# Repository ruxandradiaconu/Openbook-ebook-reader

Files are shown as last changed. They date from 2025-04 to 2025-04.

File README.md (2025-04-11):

OpenBook e-book reader
Diaconu Oana-Ruxandra - 331CC

## Diagrama bloc

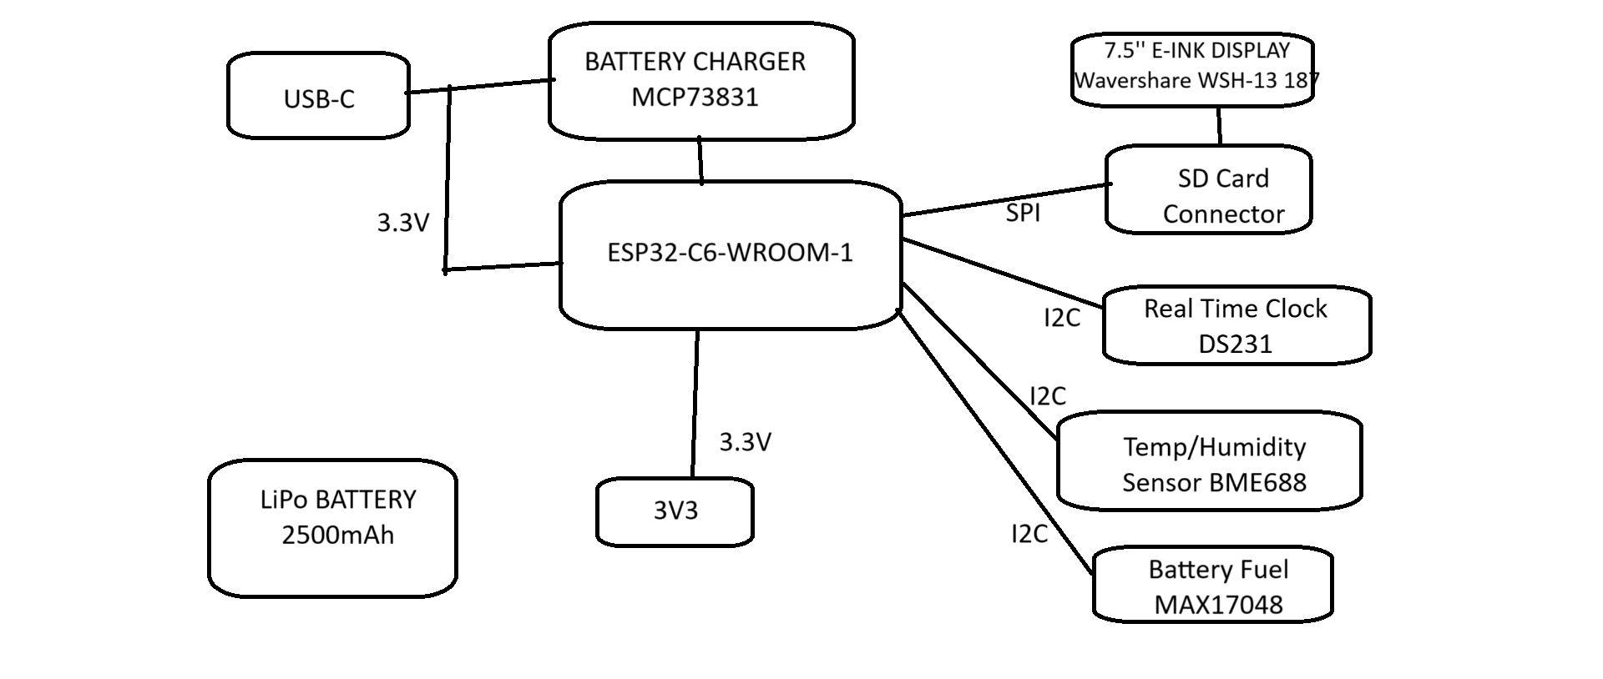
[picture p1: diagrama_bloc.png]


## BOM – Bill of Materials

| Componenta | Link | Datasheet |
|:---|:---|:---|
| 112A-TAAR-R03_ATTEND | https://store.comet.bg/en/Catalogue/Product/43497/ | https://store.comet.bg/en/Catalogue/Product/43497/ |
| 744043680IND_4828-WE-TPC_WRE | https://www.digikey.sg/en/models/1638515 | https://www.digikey.sg/en/models/1638515 |
| ADAFRUIT_LEDCHIP-LED0603 | https://www.snapeda.com/parts/KP-1608SURCK/Kingbright/view-part/?ref=search&t=LED%200603 | https://www.snapeda.com/parts/KP-1608SURCK/Kingbright/datasheet/ |
| BD5229G-TR | https://componentsearchengine.com/part-view/BD5229G-TR/ROHM%20Semiconductor | https://componentsearchengine.com/part-view/BD5229G-TR/ROHM%20Semiconductor |
| BME680 | https://www.snapeda.com/parts/BME680/Bosch/view-part/?welcome=home | https://www.snapeda.com/parts/BME680/Bosch%20Sensortec/datasheet/ |
| BUTTON_CUSYOMV1 | https://industry.panasonic.com/global/en/downloads?tab=cad&small_g_cd=203&part_no=EVQPUJ02K | https://industry.panasonic.com/global/en/downloads?tab=catalog&small_g_cd=203&part_no=EVQPUJ02K |
| CC0402MRX5R5BB106 | https://componentsearchengine.com/part-view/CC0402MRX5R5BB106/YAGEO | https://componentsearchengine.com/part-view/CC0402MRX5R5BB106/YAGEO |
| CPH3225A | https://www.snapeda.com/parts/CPH3225A/Seiko+Instruments/view-part/?ref=eda | https://www.snapeda.com/parts/CPH3225A/Seiko%20Instruments/datasheet/ |
| DS3231SN | https://www.snapeda.com/parts/DS3231SN%23/Analog+Devices/view-part/?ref=eda | https://www.snapeda.com/parts/DS3231SN%23/Analog%20Devices/datasheet/ |
| 7.5in E-ink Display | https://grabcad.com/library/7-5in-e-ink-display-assortment-1 | https://grabcad.com/library/7-5in-e-ink-display-assortment-1 |
| ESP32-C6-WROOM-1-N8 | https://www.snapeda.com/parts/ESP32-C6-WROOM-1-N8/Espressif+Systems/view-part/?ref=eda | https://www.snapeda.com/parts/ESP32-C6-WROOM-1-N8/Espressif%20Systems/datasheet/ |
| ESP32C6_VARISTORCN1812 | https://www.mouser.co.uk/ProductDetail/EPCOS-TDK/B72520T0350K062 | https://www.mouser.co.uk/ProductDetail/EPCOS-TDK/B72520T0350K062 |
| ESP32_WROVER_BME680_BME680 | https://www.snapeda.com/parts/BME680/Bosch/view-part/?welcome=home | https://www.snapeda.com/parts/BME680/Bosch%20Sensortec/datasheet/ |
| ESP32_WROVER_EAGLE-LTSPICE_CC0402 | https://componentsearchengine.com/part-view/CC0402MRX5R5BB106/YAGEO | https://componentsearchengine.com/Datasheets/2/CC0402MRX5R5BB106.pdf |
| ESP32_WROVER_EAGLE-LTSPICE_RR0402 | https://www.snapeda.com/parts/RC0402FR-07226RL/Yageo/view-part/ | https://www.snapeda.com/parts/RC0402FR-07226RL/Yageo/datasheet/ |
| ESP32_WROVER_SPARKFUN-DISCRETESEMI_MOSFET_PCH-DMG2305UX-7 | https://componentsearchengine.com/part-view/DMG2305UX-7/Diodes%20Incorporated | https://componentsearchengine.com/part-view/DMG2305UX-7/Diodes%20Incorporated |
| FH34SRJ-24S-0.5SH_99_ | https://componentsearchengine.com/part-view/XC6220A331MR-G/Torex |  https://componentsearchengine.com/part-view/XC6220A331MR-G/Torex |
| MAX17048G+T10 | https://www.snapeda.com/parts/MAX17048G+T10/Analog+Devices/view-part/?ref=eda | https://www.snapeda.com/parts/MAX17048G+T10/Analog%20Devices/datasheet/ |
| MBR0530 | https://ro.mouser.com/ProductDetail/KYOCERA-AVX/SD0805S020S1R0 | https://ro.mouser.com/datasheet/2/40/schottky-3165252.pdf |
| MCP73831 | https://www.digikey.com/en/models/1874108 | https://www.digikey.com/en/models/1874108 |
| PGB1010603MR | https://www.snapeda.com/parts/PGB1010603MR/Littelfuse/view-part/?ref=eda | https://www.snapeda.com/parts/PGB1010603MR/Littelfuse%20Inc./datasheet/ |
| QWIIC_CONNECTORJS-1MM | https://www.snapeda.com/parts/PRT-14417/SparkFun/view-part/ | https://www.snapeda.com/parts/PRT-14417/SparkFun%20Electronics/datasheet/ |
| RCL-CT3528 | https://stud33302.autodesk360.com/g/shares/SH30dd5QT870c25f12fc6065d74bcaa3bf24 | https://stud33302.autodesk360.com/g/shares/SH30dd5QT870c25f12fc6065d74bcaa3bf24 |
| SAMACSYS_PARTS_USB4110-GF-A | https://componentsearchengine.com/part-view/USB4110-GF-A/GCT%20(GLOBAL%20CONNECTOR%20TECHNOLOGY) | https://componentsearchengine.com/part-view/USB4110-GF-A/GCT%20(GLOBAL%20CONNECTOR%20TECHNOLOGY) |
| SI1308EDL-T1-GE3 | https://componentsearchengine.com/part-view/SI1308EDL-T1-GE3/Vishay | https://componentsearchengine.com/Datasheets/1/SI1308EDL-T1-GE3.pdf |
| SJ | https://grabcad.com/library/solder-jumpers-1 | https://grabcad.com/library/solder-jumpers-1 |
| USBLC6-2SC6Y | https://www.snapeda.com/parts/USBLC6-2SC6Y/STMicroelectronics/view-part/?ref=eda | https://www.snapeda.com/parts/USBLC6-2SC6Y/STMicroelectronics/datasheet/ |
| W25Q512JVEIQ | https://www.snapeda.com/parts/W25Q512JVEIQ/Winbond+Electronics/view-part/?ref=eda | https://www.snapeda.com/parts/W25Q512JVEIQ/Winbond%20Electronics/datasheet/ |
| XC6220A331MR-G | https://componentsearchengine.com/part-view/XC6220A331MR-G/Torex | https://componentsearchengine.com/part-view/XC6220A331MR-G/Torex |

## Descriere functionalitati hardware

###  **E-paper Display**
  - Conectat prin pinii MOSI, SCK, CS, DC, BUSY, RST
  - Permite afișarea conținutului static cu consum energetic extrem de redus
  
###  **SD Card**
  - Conectat prin CS, MOSI, MISO, SCK
  - Utilizat pentru stocarea cărților electronice și a configurațiilor

###  **Baterie Li-Po + Fuel Gauge**
  - Alimentarea principală a sistemului, conectată direct prin paduri la PCB
  - Monitorizată prin MAX17048G+T10 conectat pe I2C (SDA, SCL)

###  **BME688**
  - Senzor ambiental pentru temperatură, presiune, umiditate și gaze
  - Comunică prin aceiași pini I2C ca RTC și Fuel Gauge

###  **RTC** 
  - Oferă timp real precis, cu pin INT pentru întreruperi și pin de reset 
  - Alimentat separat prin VRTC

###  **Butoane fizice**
  - BOOT, IO_CHANGE și RESET
  - Permite controlul funcțiilor precum trecerea între pagini, pornirea dispozitivului, sau activarea bootloader-ului pentru upload firmware

###  **USB-C Conector**
  - Permite programarea și încărcarea dispozitivului.
  - Include protecții ESD și varistor pentru protecția circuitului.

### Specificații de comunicație:

- **SPI** pentru SD card, display și memorie NOR Flash.
- **I2C** pentru RTC, senzor BME688 și fuel gauge.
- **UART** pentru debug sau comunicație serială externă.

### Estimare consum:

- În regim activ: între 80–150 mA (în funcție de e-paper și senzorii activi).
- În standby (deep sleep): sub 1 mA.
- Display-ul e-paper nu consumă curent în regim static – doar la refresh.

## Corespondenta pini ESP32-C6 - restul componentelor

| Pin ESP32-C6 | Nume net / semnal | Componentă asociată | Funcție / Motivare |
|---|---|---|---|
| GPIO0 | IO/BOOT | Buton BOOT | Activare bootloader pentru flash |
| GPIO1 | SS_SD | SD Card | Chip select pentru card SD |
| GPIO3 | MOSI | SD Card + E-Paper | Comunicare SPI |
| GPIO4 | MISO | SD Card | Citire date SPI |
| GPIO5 | SCK | SD Card + E-Paper | Clock SPI |
| GPIO6 | EPD_CS | E-Paper Display | Selectare ecran SPI |
| GPIO7 | EPD_DC | E-Paper Display | Data/Command pentru ecran |
| GPIO8 | EPD_BUSY | E-Paper Display | Semnal BUSY de la ecran |
| GPIO9 | EPD_RST | E-Paper Display | Reset hardware ecran |
| GPIO10 | FLASH_CS | NOR Flash W25Q512 | Chip select memorie SPI |
| GPIO16 | TXD0 | UART Serial | Transmisie serială |
| GPIO17 | RXD0 | UART Serial | Recepție serială |
| GPIO18 | SDA | RTC, BME688, Fuel Gauge | I2C Data |
| GPIO19 | SCL | RTC, BME688, Fuel Gauge | I2C Clock |
| GPIO20 | INT_RTC | RTC | Interrupere alarmă |
| GPIO21 | IO/CHANGE | Buton IO_CHANGE | Detecție apăsare buton |
| GPIO22 | RTC_RST | RTC | Reset RTC |
| GPIO23 | VRTC | RTC | Tensiune RTC |
| GPIO44 | RESE | Reset ESP / Sisteme externe | Reset logic suplimentar |
| GPIO45 | GDR | E-Paper Driver | Gate Driver enable |

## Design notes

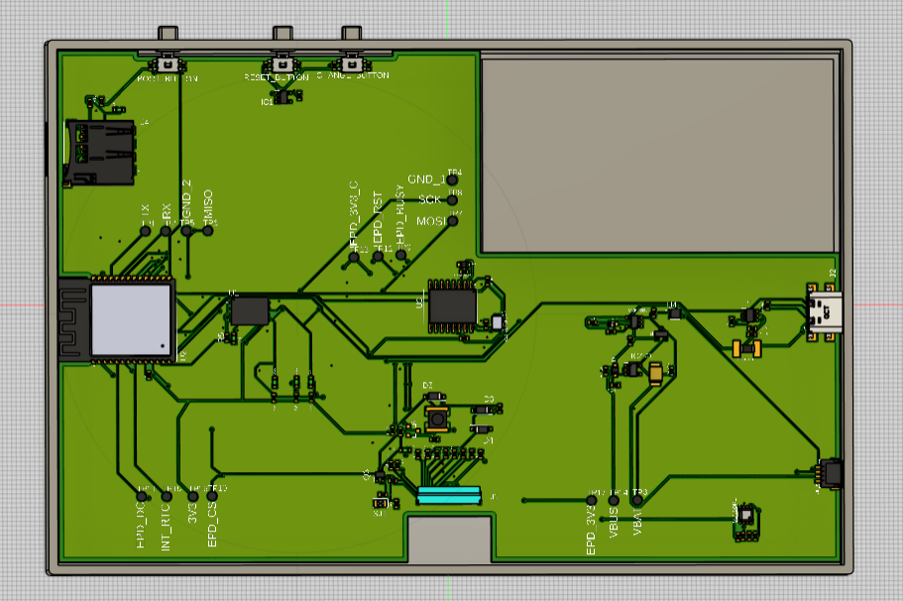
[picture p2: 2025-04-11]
Images/final_inside_completed.png

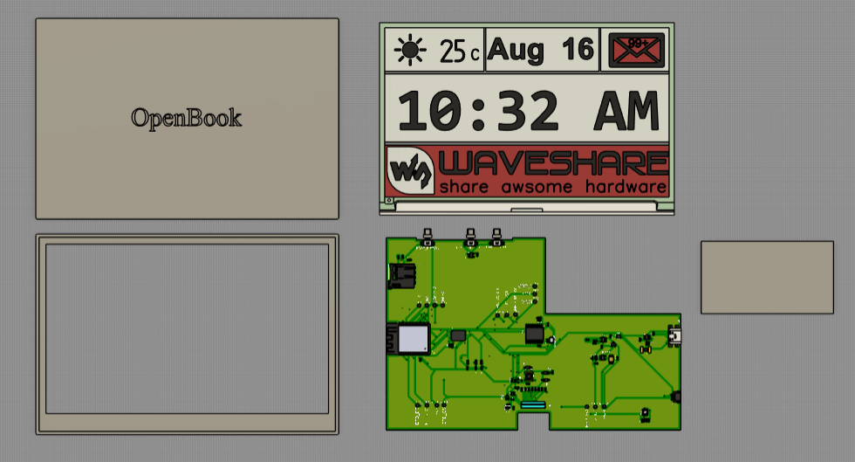
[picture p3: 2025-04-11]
Images/final_exploded_view.png

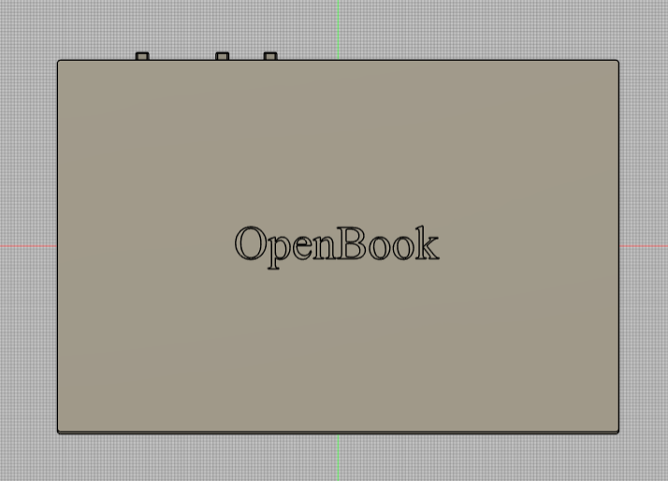
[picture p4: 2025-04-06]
Images/Screenshot 2025-04-06 185446.png

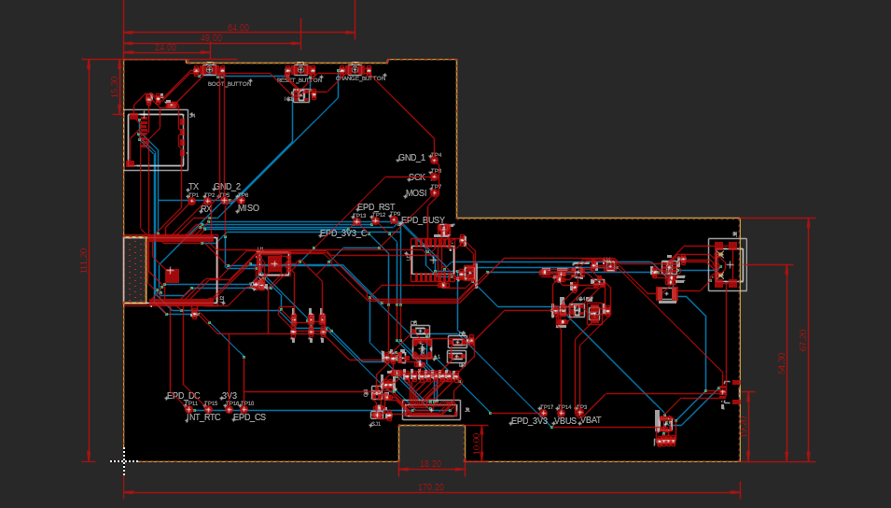
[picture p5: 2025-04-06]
Images/Screenshot 2025-04-06 185516.png

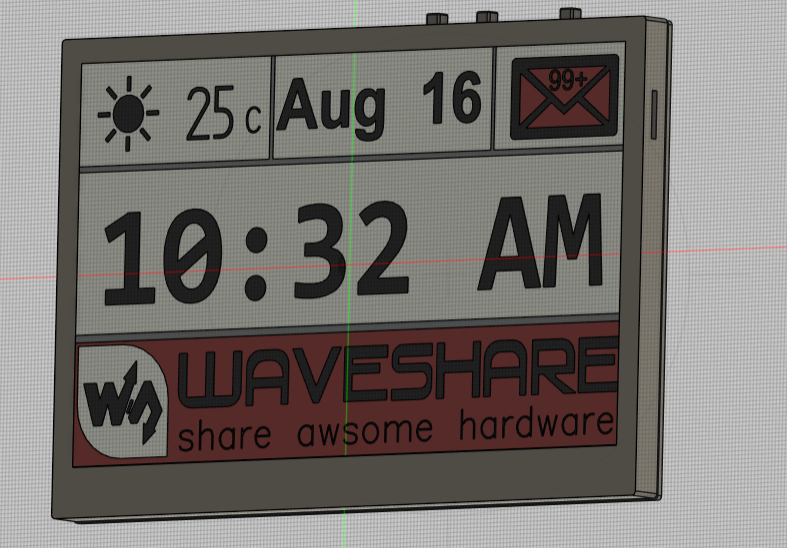
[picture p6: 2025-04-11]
Images/final_display_view.png

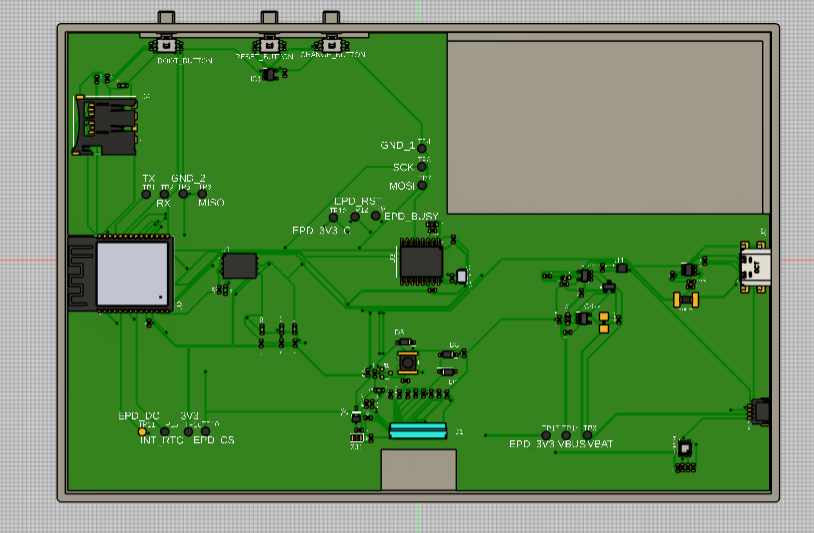
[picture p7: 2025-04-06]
Images/Screenshot 2025-04-06 185214.png

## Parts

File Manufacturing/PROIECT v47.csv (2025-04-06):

Qty | Value | Device | Package | Parts | Description | 3D_3V3 | 3D_EPD_3V3 | 3D_EPD_3V3_C | 3D_EPD_BUSY | 3D_EPD_CS | 3D_EPD_DC | 3D_EPD_RST | 3D_GND | 3D_GND2 | 3D_INT_RTC | 3D_MISO | 3D_MOSI | 3D_RX | 3D_SCK | 3D_TX | 3D_VBAT | 3D_VBUS | ARROW_PART_NUMBER | ARROW_PRICE-STOCK | AVAILABILITY | CENTROID_NOT_SPECIFIED | CHECK_PRICES | COPYRIGHT | DATASHEET | DESCRIPTION | DIGIKEY_DESCRIPTION | DIGIKEY_PART_NUMBER | DMG2305UX-7 | HEIGHT | LEAD_FREE | MANUFACTURER_NAME | MANUFACTURER_PART_NUMBER | MF | MFR_NAME | MOUSER_PART_NUMBER | MOUSER_PRICE-STOCK | MOUSER_TESTING_PART_NUMBER | MOUSER_TESTING_PRICE-STOCK | MP | MPN | PACKAGE | POPULARITY | PREFIX | PRICE | PROD_ID | PURCHASE-URL | ROHS | SNAPEDA_LINK | SPICEMODEL | SPICEPREFIX | TEMPERATURE_RANGE_HIGH | TEMPERATURE_RANGE_LOW | TP_SIGNAL_NAME | VALUE
1 |  | ADAFRUIT_LEDCHIP-LED0603 | ADAFRUIT_CHIP-LED0603 | CHG_LED | LED
3 |  | BUTTON_CUSYOMV1 | MYBUTTON | BOOT_BUTTON, CHANGE_BUTTON, RESET_BUTTON
3 |  | MBR0530''' | SOD3716X135N | D3, D4, D5 | ON SEMICONDUCTOR - MBR0530 - DIODE, SCHOTTKY, 0.5A, 30V, SOD-123
1 |  | SJ | SJ | SJ1 | SMD solder JUMPER |  |  |  |  |  |  |  |  |  |  |  |  |  |  |  |  |  |  |  |  |  |  |  |  |  |  |  |  |  |  |  |  |  |  |  |  |  |  |  |  |  | 3
1 | 0.1uF/50V | EAGLE-LTSPICE_CC0402 | EAGLE-LTSPICE_C0402 | EPD_C5 | CAPACITOR, European symbol |  |  |  |  |  |  |  |  |  |  |  |  |  |  |  |  |  |  |  |  |  |  |  |  |  |  |  |  |  |  |  |  |  |  |  |  |  |  |  |  |  |  |  |  |  |  |  |  | NONE | C
1 | 0.47 | ESP32_WROVER_EAGLE-LTSPICE_R | ESP32_WROVER_EAGLE-LTSPICE_R0402 | R3 | RESISTOR, European symbol
1 | 100k | ESP32_WROVER_EAGLE-LTSPICE_R | ESP32_WROVER_EAGLE-LTSPICE_R0402 | R1_PWRUSB | RESISTOR, European symbol
6 | 100nF | EAGLE-LTSPICE_CC0402 | EAGLE-LTSPICE_C0402 | C5, C6, C8, C9, C10, C_DELAY | CAPACITOR, European symbol |  |  |  |  |  |  |  |  |  |  |  |  |  |  |  |  |  |  |  |  |  |  |  |  |  |  |  |  |  |  |  |  |  |  |  |  |  |  |  |  |  |  |  |  |  |  |  |  | NONE | C
3 | 100nF | ESP32_WROVER_EAGLE-LTSPICE_C | ESP32_WROVER_EAGLE-LTSPICE_C0402 | C1, C2, C4_USB | CAPACITOR, European symbol
1 | 100uF TANT | RCL_CPOL-EUCT3528 | RCL_CT3528 | C3 | POLARIZED CAPACITOR, European symbol |  |  |  |  |  |  |  |  |  |  |  |  |  |  |  |  |  |  |  |  |  |  |  |  |  |  |  |  |  |  |  |  |  |  |  |  |  |  |  |  |  | 0 |  |  |  |  |  |  |  | C
16 | 10K | ESP32_WROVER_EAGLE-LTSPICE_R | ESP32_WROVER_EAGLE-LTSPICE_R0402 | R1, R1_PINH, R1_PINH1, R2_PINH, R2_PINH1, R4, R5, R6, R7, R8, R9, R10, R_BOOT, R_CHANGE, R_CL1, R_RESET | RESISTOR, European symbol
1 | 10uF | EAGLE-LTSPICE_CC0402 | EAGLE-LTSPICE_C0402 | C7 | CAPACITOR, European symbol |  |  |  |  |  |  |  |  |  |  |  |  |  |  |  |  |  |  |  |  |  |  |  |  |  |  |  |  |  |  |  |  |  |  |  |  |  |  |  |  |  |  |  |  |  |  |  |  | NONE | C
1 | 112A-TAAR-R03_ATTEND | 112A-TAAR-R03_ATTEND | 112ATAARR03ATTEND | J4 | Micro SD Card Socket, Push-Push Type, Top Mount, SMT, H=1.83mm, 10u |  |  |  |  |  |  |  |  |  |  |  |  |  |  |  |  |  |  |  |  |  |  |  |  | Micro SD Card Socket | Push-Push Type | Top Mount | SMT | H=1.83mm | 10u |  |  |  | 1.9mm |  | ATTEND | 112A-TAAR-R03 ATTEND
1 | 15 | ESP32_WROVER_EAGLE-LTSPICE_R | ESP32_WROVER_EAGLE-LTSPICE_R0402 | R_CAPACITOR | RESISTOR, European symbol
9 | 1uF/50V | EAGLE-LTSPICE_CC0402 | EAGLE-LTSPICE_C0402 | EPD_C1, EPD_C2, EPD_C6, EPD_C7, EPD_C8, EPD_C9, EPD_C10, EPD_C11, EPD_C12 | CAPACITOR, European symbol |  |  |  |  |  |  |  |  |  |  |  |  |  |  |  |  |  |  |  |  |  |  |  |  |  |  |  |  |  |  |  |  |  |  |  |  |  |  |  |  |  |  |  |  |  |  |  |  | NONE | C
1 | 2.2 | ESP32_WROVER_EAGLE-LTSPICE_R | ESP32_WROVER_EAGLE-LTSPICE_R0402 | R2 | RESISTOR, European symbol
1 | 200 | ESP32_WROVER_EAGLE-LTSPICE_R | ESP32_WROVER_EAGLE-LTSPICE_R0402 | R1_BAT | RESISTOR, European symbol
2 | 20V/4.2A/52mO/1.4W | ESP32_WROVER_SPARKFUN-DISCRETESEMI_MOSFET_PCH-DMG2305UX-7 | ESP32_WROVER_SPARKFUN-DISCRETESEMI_SOT23-3 | Q1, Q2 | P-channel MOSFETs |  |  |  |  |  |  |  |  |  |  |  |  |  |  |  |  |  |  |  |  |  |  |  |  |  |  |  |  |  |  |  |  |  |  |  |  |  |  |  |  |  |  |  |  | TRAN-14388 |  |  |  |  |  |  |  |  | 20V/4.2A/52mO/1.4W
1 | 2K | ESP32_WROVER_EAGLE-LTSPICE_R | ESP32_WROVER_EAGLE-LTSPICE_R0402 | R2_BAT | RESISTOR, European symbol
2 | 4.7uF | EAGLE-LTSPICE_CC0402 | EAGLE-LTSPICE_C0402 | C1_BAT, C2_BAT | CAPACITOR, European symbol |  |  |  |  |  |  |  |  |  |  |  |  |  |  |  |  |  |  |  |  |  |  |  |  |  |  |  |  |  |  |  |  |  |  |  |  |  |  |  |  |  |  |  |  |  |  |  |  | NONE | C
3 | 4.7uF | ESP32_WROVER_EAGLE-LTSPICE_C | ESP32_WROVER_EAGLE-LTSPICE_C0402 | C1_BAT1, C1_BAT2, C5_USB | CAPACITOR, European symbol
1 | 4.7uF/25V | EAGLE-LTSPICE_CC0402 | EAGLE-LTSPICE_C0402 | C4 | CAPACITOR, European symbol |  |  |  |  |  |  |  |  |  |  |  |  |  |  |  |  |  |  |  |  |  |  |  |  |  |  |  |  |  |  |  |  |  |  |  |  |  |  |  |  |  |  |  |  |  |  |  |  | NONE | C
2 | 5K1 | ESP32_WROVER_EAGLE-LTSPICE_R | ESP32_WROVER_EAGLE-LTSPICE_R0402 | R2-USB1, R2_USB | RESISTOR, European symbol
1 | 68uH | 744043680IND_4828-WE-TPC_WRE | IND_4828-WE-TPC_WRE | L1 |  |  |  |  |  |  |  |  |  |  |  |  |  |  |  |  |  |  |  |  |  |  |  | Copyright (C) 2024 Ultra Librarian. All rights reserved. |  |  |  |  |  |  |  |  | 744043680 |  | Wurth Electronics
1 | BD5229G-TR | BD5229G-TR | SOT95P280X125-5N | IC1 | Voltage Detector with Adjustable Delay Time: CMOS processes are utilized to develop high precision, low current consumption CMOS reset ICs that allow arbitrary setting of the delay time. The extensive lineup includes both Nch Open Drain and CMOS output types in a wide range of detection voltages (from 2.3V to 6.0V, in 0.1V steps), enabling selection of the ideal solution based on customer requirements. In addition, the entire series is of course both lead-free and RoHS-compliant. |  |  |  |  |  |  |  |  |  |  |  |  |  |  |  |  |  |  |  |  |  |  |  |  | Voltage Detector with Adjustable Delay Time: CMOS processes are utilized to develop high precision | low current consumption CMOS reset ICs that allow arbitrary setting of the delay time. The extensive lineup includes both Nch Open Drain and CMOS output types in a wide range of detection voltages (from 2.3V to 6.0V | in 0.1V steps) | enabling selection of the ideal solution based on customer requirements. In addition | the entire series is of course both lead-free and RoHS-compliant. |  |  |  | 1.25mm |  | ROHM Semiconductor | BD5229G-TR |  |  | 755-BD5229G-TR | https://www.mouser.co.uk/ProductDetail/ROHM-Semiconductor/BD5229G-TR?qs=4kLU8WoGk0vvnhrrYwdszw%3D%3D
1 | CPH3225A | CPH3225A | CAPCP3225X100N | C10_SUPERCAP | Cap 0.011F 3.3V 1210 Flat Check availability |  |  |  |  |  |  |  |  |  |  |  |  |  |  |  |  |  |  |  | Not in stock |  | https://www.snapeda.com/parts/CPH3225A/Seiko+Instruments/view-part/?ref=eda |  |  | 11 mF (EDLC) Supercapacitor 3.3 V 1210 (3225 Metric) - - |  |  |  |  |  |  |  | Seiko Instruments |  |  |  |  |  | CPH3225A |  | 1210 Seiko |  |  | None |  | https://www.snapeda.com/api/url_track_click_mouser/?unipart_id=562593&manufacturer=Seiko Instruments&part_name=CPH3225A&search_term=None |  | https://www.snapeda.com/parts/CPH3225A/Seiko+Instruments/view-part/?ref=snap
1 | DS3231SN# | DS3231SN# | SOIC127P1032X265-16N | U3 | Real Time Clock Serial 16-Pin SOIC W T/R Check availability |  |  |  |  |  |  |  |  |  |  |  |  |  |  |  |  |  |  |  | In Stock |  | https://www.snapeda.com/parts/DS3231SN%23/Analog+Devices/view-part/?ref=eda |  |  | Extremely Accurate I²C-Integrated RTC/TCXO/Crystal |  |  |  |  |  |  |  | Analog Devices |  |  |  |  |  | DS3231SN# |  | SOIC-16 Maxim |  |  | None |  | https://www.snapeda.com/api/url_track_click_mouser/?unipart_id=99048&manufacturer=Analog Devices&part_name=DS3231SN#&search_term=None |  | https://www.snapeda.com/parts/DS3231SN%23/Analog+Devices/view-part/?ref=snap
1 | ESP32-C6-WROOM-1-N8 | ESP32-C6-WROOM-1-N8 | XCVR_ESP32-C6-WROOM-1-N8 | U2 | Check availability |  |  |  |  |  |  |  |  |  |  |  |  |  |  |  |  |  |  |  | In Stock |  | https://www.snapeda.com/parts/ESP32-C6-WROOM-1-N8/Espressif+Systems/view-part/?ref=eda |  |  | Multiprotocol Modules ESP32-C6 module | Wi-Fi 6 in 2.4 GHz band | Bluetooth 5 | Zigbee 3.0 and Thread. ESP34-WROOM Compatible - ENGINEERING SAMPLE |  |  |  |  |  |  |  | Espressif Systems |  |  |  |  |  | ESP32-C6-WROOM-1-N8 |  | None |  |  | None |  |  |  | https://www.snapeda.com/parts/ESP32-C6-WROOM-1-N8/Espressif+Systems/view-part/?ref=snap
1 | ESP32C6_VARISTORCN1812 | ESP32C6_VARISTORCN1812 | ESP32C6_VARISTOR_CT/CN1812 | PFMF.050.1 | VARISTOR |  |  |  |  |  |  |  |  |  |  |  |  |  |  |  |  |  |  |  |  |  |  |  |  |  |  |  |  |  |  |  |  |  |  |  |  |  |  |  |  |  | 0
2 | ESP32_WROVER_AVX---SD0805S020S1R0_AVX_SD0805S020S1R0_0_0AVX_SD0805S020S1R0_0_0 | ESP32_WROVER_AVX---SD0805S020S1R0_AVX_SD0805S020S1R0_0_0AVX_SD0805S020S1R0_0_0 | ESP32_WROVER_AVX---SD0805S020S1R0_AVX_SD0805S020S1R0_0 | D2, D7 | Schottky Barrier Rectifier Diode |  |  |  |  |  |  |  |  |  |  |  |  |  |  |  |  |  |  |  |  | No |  |  | http://datasheets.avx.com/schottky.pdf |  | DIODE SCHOTTKY 20V 1A 0805 | 478-7800-1-ND |  |  | yes |  |  | AVX |  | 581-SD0805S020S1R0 |  |  |  |  |  | 0805 (2012 metric) |  | D |  |  |  | yes |  |  |  | +125°C | -55°C
1 | ESP32_WROVER_BME680_BME680 | ESP32_WROVER_BME680_BME680 | ESP32_WROVER_BME680_PSON80P300X300X100-8N | SENSOR2 | Integrated Environmental Unit |  |  |  |  |  |  |  |  |  |  |  |  |  |  |  |  |  |  |  | Unavailable |  |  |  |  | Integrated Environmental Unit |  |  |  |  |  |  |  | Bosch Sensortec |  |  |  |  |  | BME680 |  | LGA-8 Bosch Tools |  |  | None
1 | ESP32_WROVER_SPARKFUN-IC-POWER_MCP73831 | ESP32_WROVER_SPARKFUN-IC-POWER_MCP73831 | ESP32_WROVER_SPARKFUN-IC-POWER_SOT23-5 | MCP73831 | MCP73831T Li-Ion, Li-Pol Controller |  |  |  |  |  |  |  |  |  |  |  |  |  |  |  |  |  |  |  |  |  |  |  |  |  |  |  |  |  |  |  |  |  |  |  |  |  |  |  |  |  |  |  |  | IC-09995
1 | FH34SRJ-24S-0.5SH_99_ | FH34SRJ-24S-0.5SH_99_ | FH34SRJ24S05SH99 | J1 | (0.50mm) Surface Mount, Right Angle |  |  |  |  |  |  |  |  |  |  |  |  |  |  |  |  |  |  |  |  |  |  |  |  | 24 Position FFC | FPC Connector Contacts | (0.50mm) Surface Mount | Right Angle |  |  |  | 1.1mm |  | Hirose | FH34SRJ-24S-0.5SH(99) |  |  | 798-FH34SRJ24S05SH99 | https://www.mouser.co.uk/ProductDetail/Hirose-Connector/FH34SRJ-24S-0.5SH99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
1 | MAX17048G+T10 | MAX17048G+T10 | SON50P200X200X80-9N | U4 | Check availability |  |  |  |  |  |  |  |  |  |  |  |  |  |  |  |  |  |  |  | In Stock |  | https://www.snapeda.com/parts/MAX17048G+T10/Analog+Devices/view-part/?ref=eda |  |  | 3µA 1-Cell/2-Cell Fuel Gauge with ModelGauge |  |  |  |  |  |  |  | Analog Devices |  |  |  |  |  | MAX17048G+T10 |  | TDFN-8 Maxim |  |  | None |  | https://www.snapeda.com/api/url_track_click_mouser/?unipart_id=329239&manufacturer=Analog Devices&part_name=MAX17048G+T10&search_term=None |  | https://www.snapeda.com/parts/MAX17048G+T10/Analog+Devices/view-part/?ref=snap
6 | PGB1010603MR''' | PGB1010603MR''' | DIOC1608X36N | D6, D8, D9, D10, D11, D12 | Check availability
1 | QWIIC_RIGHT_ANGLE | QWIIC_CONNECTORJS-1MM | JST04_1MM_RA | J3 | SparkFun I2C Standard Qwiic Connector |  |  |  |  |  |  |  |  |  |  |  |  |  |  |  |  |  |  |  |  |  |  |  |  |  |  |  |  |  |  |  |  |  |  |  |  |  |  |  |  |  |  |  |  | CONN-13694 |  |  |  |  |  |  |  |  | QWIIC_RIGHT_ANGLE
1 | SAMACSYS_PARTS_USB4110-GF-A | SAMACSYS_PARTS_USB4110-GF-A | SAMACSYS_PARTS_USB4110GFA | J2 | CONN USB 2.0 TYPE-C R/A SMT |  |  |  |  |  |  |  |  |  |  |  |  |  |  |  |  |  |  |  |  |  |  |  |  | CONN USB 2.0 TYPE-C R/A SMT |  |  |  | 3.26mm |  | GCT (GLOBAL CONNECTOR TECHNOLOGY) | USB4110-GF-A |  |  | 640-USB4110-GF-A | https://www.mouser.co.uk/ProductDetail/GCT/USB4110-GF-A?qs=KUoIvG%2F9IlYiZvIXQjyJeA%3D%3D
1 | SI1308EDL-T1-GE3 | SI1308EDL-T1-GE3 | SOT65P210X110-3N | Q3 | MOSFET N-Ch 30V 1.5A TrenchFET SC70 Vishay Si1308EDL-T1-GE3 N-channel MOSFET Transistor, 1.5 A, 30 V, 3-Pin SC-70 |  |  |  |  |  |  |  |  |  |  |  |  |  |  |  |  |  |  |  | In Stock |  | https://www.snapeda.com/parts/SI1308EDL-T1-GE3/Vishay+Siliconix/view-part/?ref=eda |  |  | Si1308EDL-T1-GE3 N-channel MOSFET Transistor | 1.5 A | 30 V | 3-Pin SC-70 | Siliconix / Vishay SI1308EDL-T1-GE3 |  |  |  |  |  |  |  | Vishay Siliconix |  |  |  |  |  | SI1308EDL-T1-GE3 |  | SOT-323 Vishay Semiconductor |  |  | None |  | https://www.snapeda.com/api/url_track_click_mouser/?unipart_id=274603&manufacturer=Vishay Siliconix&part_name=SI1308EDL-T1-GE3&search_term=None |  | https://www.snapeda.com/parts/SI1308EDL-T1-GE3/Vishay+Siliconix/view-part/?ref=snap
1 | TPTP20R | TPTP20R | TP20R | TP14 | Test pad |  |  |  |  |  |  |  |  |  |  |  |  |  |  |  |  | VBUS |  |  |  |  |  |  |  |  |  |  |  |  |  |  |  |  |  |  |  |  |  |  |  |  | 2
1 | TPTP20R | TPTP20R | TP20R | TP3 | Test pad |  |  |  |  |  |  |  |  |  |  |  |  |  |  |  | VBAT |  |  |  |  |  |  |  |  |  |  |  |  |  |  |  |  |  |  |  |  |  |  |  |  |  | 2
1 | TPTP20R | TPTP20R | TP20R | TP1 | Test pad |  |  |  |  |  |  |  |  |  |  |  |  |  |  | TX |  |  |  |  |  |  |  |  |  |  |  |  |  |  |  |  |  |  |  |  |  |  |  |  |  |  | 2
1 | TPTP20R | TPTP20R | TP20R | TP8 | Test pad |  |  |  |  |  |  |  |  |  |  |  |  |  | SCK |  |  |  |  |  |  |  |  |  |  |  |  |  |  |  |  |  |  |  |  |  |  |  |  |  |  |  | 2
1 | TPTP20R | TPTP20R | TP20R | TP2 | Test pad |  |  |  |  |  |  |  |  |  |  |  |  | RX |  |  |  |  |  |  |  |  |  |  |  |  |  |  |  |  |  |  |  |  |  |  |  |  |  |  |  |  | 2
1 | TPTP20R | TPTP20R | TP20R | TP7 | Test pad |  |  |  |  |  |  |  |  |  |  |  | MOSI |  |  |  |  |  |  |  |  |  |  |  |  |  |  |  |  |  |  |  |  |  |  |  |  |  |  |  |  |  | 2
1 | TPTP20R | TPTP20R | TP20R | TP6 | Test pad |  |  |  |  |  |  |  |  |  |  | MISO |  |  |  |  |  |  |  |  |  |  |  |  |  |  |  |  |  |  |  |  |  |  |  |  |  |  |  |  |  |  | 2
1 | TPTP20R | TPTP20R | TP20R | TP15 | Test pad |  |  |  |  |  |  |  |  |  | INT_RTC |  |  |  |  |  |  |  |  |  |  |  |  |  |  |  |  |  |  |  |  |  |  |  |  |  |  |  |  |  |  |  | 2
1 | TPTP20R | TPTP20R | TP20R | TP5 | Test pad |  |  |  |  |  |  |  |  | GND_2 |  |  |  |  |  |  |  |  |  |  |  |  |  |  |  |  |  |  |  |  |  |  |  |  |  |  |  |  |  |  |  |  | 2
1 | TPTP20R | TPTP20R | TP20R | TP4 | Test pad |  |  |  |  |  |  |  | GND_1 |  |  |  |  |  |  |  |  |  |  |  |  |  |  |  |  |  |  |  |  |  |  |  |  |  |  |  |  |  |  |  |  |  | 2
1 | TPTP20R | TPTP20R | TP20R | TP12 | Test pad |  |  |  |  |  |  | EPD_RST |  |  |  |  |  |  |  |  |  |  |  |  |  |  |  |  |  |  |  |  |  |  |  |  |  |  |  |  |  |  |  |  |  |  | 2
1 | TPTP20R | TPTP20R | TP20R | TP11 | Test pad |  |  |  |  |  | EPD_DC |  |  |  |  |  |  |  |  |  |  |  |  |  |  |  |  |  |  |  |  |  |  |  |  |  |  |  |  |  |  |  |  |  |  |  | 2
1 | TPTP20R | TPTP20R | TP20R | TP10 | Test pad |  |  |  |  | EPD_CS |  |  |  |  |  |  |  |  |  |  |  |  |  |  |  |  |  |  |  |  |  |  |  |  |  |  |  |  |  |  |  |  |  |  |  |  | 2
1 | TPTP20R | TPTP20R | TP20R | TP9 | Test pad |  |  |  | EPD_BUSY |  |  |  |  |  |  |  |  |  |  |  |  |  |  |  |  |  |  |  |  |  |  |  |  |  |  |  |  |  |  |  |  |  |  |  |  |  | 2
1 | TPTP20R | TPTP20R | TP20R | TP13 | Test pad |  |  | EPD_3V3_C |  |  |  |  |  |  |  |  |  |  |  |  |  |  |  |  |  |  |  |  |  |  |  |  |  |  |  |  |  |  |  |  |  |  |  |  |  |  | 2
1 | TPTP20R | TPTP20R | TP20R | TP17 | Test pad |  | EPD_3V3 |  |  |  |  |  |  |  |  |  |  |  |  |  |  |  |  |  |  |  |  |  |  |  |  |  |  |  |  |  |  |  |  |  |  |  |  |  |  |  | 2
1 | TPTP20R | TPTP20R | TP20R | TP16 | Test pad | 3V3 |  |  |  |  |  |  |  |  |  |  |  |  |  |  |  |  |  |  |  |  |  |  |  |  |  |  |  |  |  |  |  |  |  |  |  |  |  |  |  |  | 2
1 | USBLC6-2SC6Y | USBLC6-2SC6Y | SOT95P280X145-6N | D1 | Low Cap. ESD Protection Auto SOT-23-6 STMicroelectronics USBLC6-2SC6Y, Dual Uni-Directional TVS Diode Array, 6-Pin SOT-23 |  |  |  |  |  |  |  |  |  |  |  |  |  |  |  |  |  |  |  | In Stock |  | https://www.snapeda.com/parts/USBLC6-2SC6Y/STMicroelectronics/view-part/?ref=eda |  |  | 17V Clamp 5A (8/20µs) Ipp Tvs Diode Surface Mount SOT-23-6 |  |  |  |  |  |  |  | STMicroelectronics |  |  |  |  |  | USBLC6-2SC6Y |  | SOT-23-6 STMicroelectronics |  |  | None |  |  |  | https://www.snapeda.com/parts/USBLC6-2SC6Y/STMicroelectronics/view-part/?ref=snap
1 | W25Q512JVEIQ | W25Q512JVEIQ | SON127P600X800X80-9N | U1 | Check availability |  |  |  |  |  |  |  |  |  |  |  |  |  |  |  |  |  |  |  | In Stock |  | https://www.snapeda.com/parts/W25Q512JVEIQ/Winbond+Electronics/view-part/?ref=eda |  |  | FLASH - NOR Memory IC 512Mb (64M x 8) SPI - Quad I/O 133 MHz 8-WSON (8x6) |  |  |  |  |  |  |  | Winbond Electronics |  |  |  |  |  | W25Q512JVEIQ |  | Package |  |  | None |  |  |  | https://www.snapeda.com/parts/W25Q512JVEIQ/Winbond+Electronics/view-part/?ref=snap
1 | XC6220A331MR-G | XC6220A331MR-G | SOT95P280X120-5N | IC4 | LDO Voltage Regulators |  |  |  |  |  |  |  |  |  |  |  |  |  |  |  |  |  |  |  |  |  |  |  |  | LDO Voltage Regulators |  |  |  | 1.2mm |  | Torex | XC6220A331MR-G |  |  | 865-XC6220A331MR-G | https://www.mouser.co.uk/ProductDetail/Torex-Semiconductor/XC6220A331MR-G?qs=AsjdqWjXhJ8ZSWznL1J0gg%3D%3D

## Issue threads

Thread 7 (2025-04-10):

Pcb 2D - Poligon

mariadobre1, 2025-04-10:
Suprafața de sub antena modulului ESP32 nu trebuie inclusă în planul de masă și nu este voie să se ruteze semnale pe sub antenă.
Suprafața PCB-ului de sub antena modulului ESP32 trebuie decupată pentru a crea cât mai puține interferențe cu semnalul radio
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

Closed 2025-04-11.

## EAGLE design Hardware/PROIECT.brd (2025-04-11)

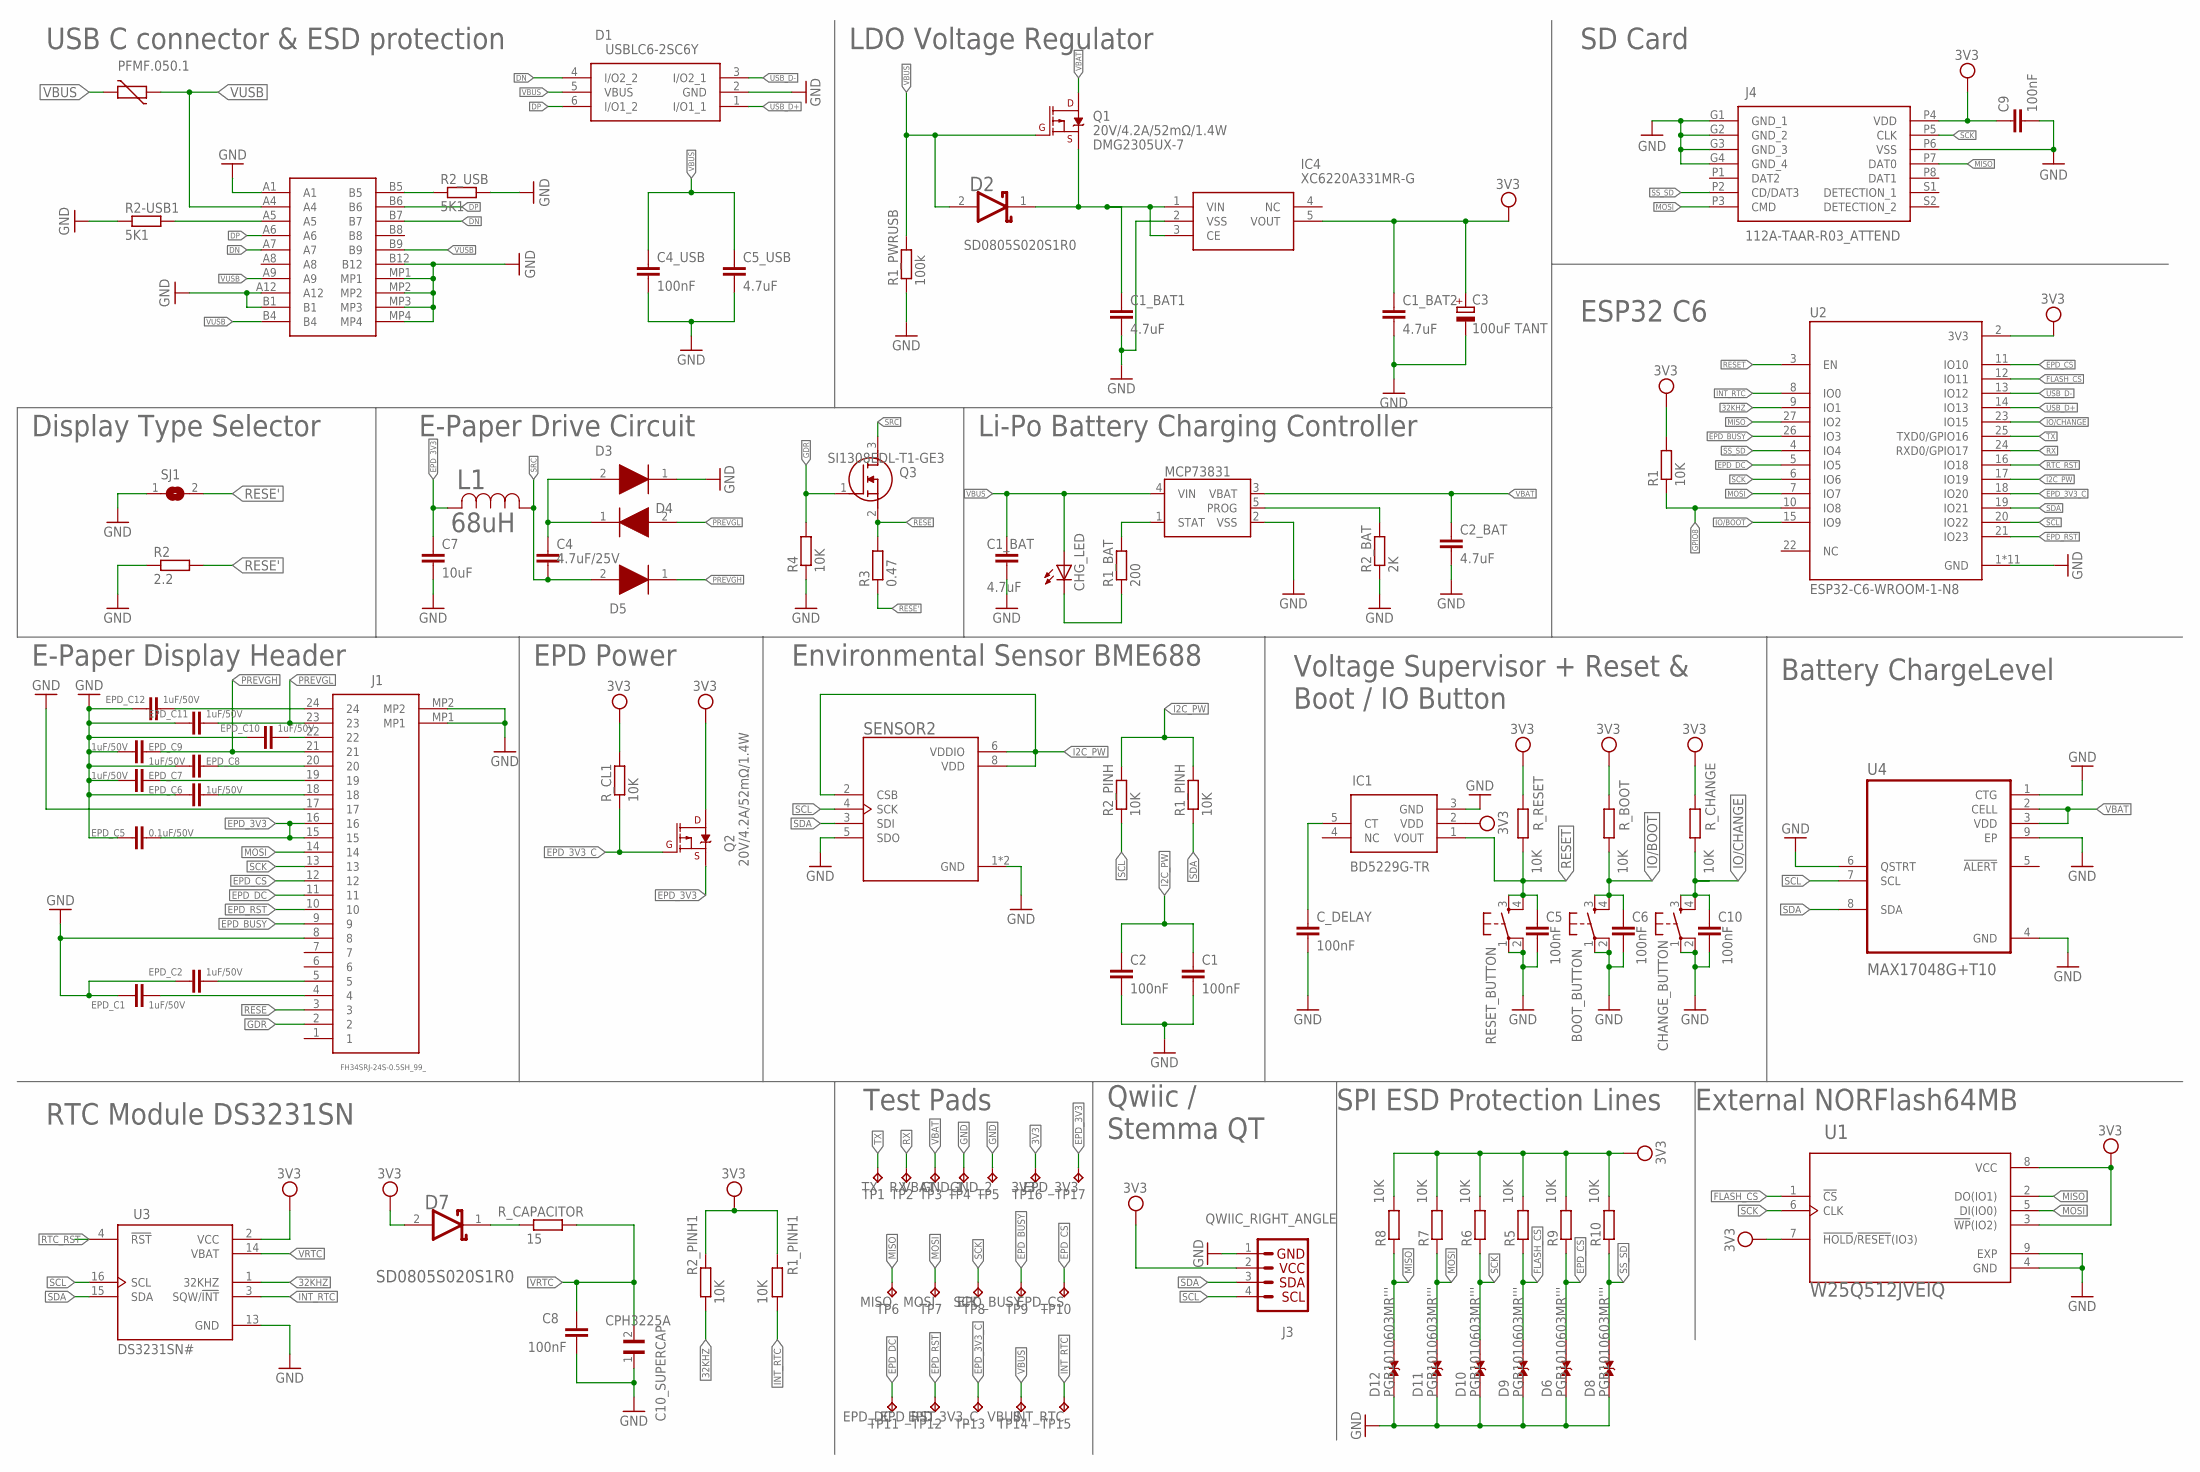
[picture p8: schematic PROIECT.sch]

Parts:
BOOT_BUTTON: BUTTON_CUSYOMV1; MYBUTTON
C1, C2, C4_USB: 100nF; ESP32_WROVER_EAGLE-LTSPICE_C0402
C1_BAT, C2_BAT: 4.7uF; EAGLE-LTSPICE_C0402
C1_BAT1, C1_BAT2, C5_USB: 4.7uF; ESP32_WROVER_EAGLE-LTSPICE_C0402
C3: 100uF TANT; RCL_CT3528
C4: 4.7uF/25V; EAGLE-LTSPICE_C0402
C5, C6, C8, C9, C10: 100nF; EAGLE-LTSPICE_C0402
C7: 10uF; EAGLE-LTSPICE_C0402
C10_SUPERCAP: CPH3225A; CAPCP3225X100N
CHANGE_BUTTON: BUTTON_CUSYOMV1; MYBUTTON
CHG_LED: ADAFRUIT_LEDCHIP-LED0603; ADAFRUIT_CHIP-LED0603
C_DELAY: 100nF; EAGLE-LTSPICE_C0402
D1: USBLC6-2SC6Y; SOT95P280X145-6N
D2, D7: ESP32_WROVER_AVX---SD0805S020S1R0_AVX_SD0805S020S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; ESP32_WROVER_AVX---SD0805S020S1R0_AVX_SD0805S020S1R0_0
D3, D4, D5: MBR0530'''; SOD3716X135N
D6, D8, D9, D10, D11, D12: PGB1010603MR'''; DIOC1608X36N
EPD_C1, EPD_C2, EPD_C6, EPD_C7, EPD_C8, EPD_C9, EPD_C10, EPD_C11, EPD_C12: 1uF/50V; EAGLE-LTSPICE_C0402
EPD_C5: 0.1uF/50V; EAGLE-LTSPICE_C0402
IC1: BD5229G-TR; SOT95P280X125-5N
IC4: XC6220A331MR-G; SOT95P280X120-5N
J1: FH34SRJ-24S-0.5SH_99_; FH34SRJ24S05SH99
J2: SAMACSYS_PARTS_USB4110-GF-A; SAMACSYS_PARTS_USB4110GFA
J3: QWIIC_RIGHT_ANGLE; JST04_1MM_RA
J4: 112A-TAAR-R03_ATTEND; 112ATAARR03ATTEND
L1: 68uH; IND_4828-WE-TPC_WRE
MCP73831: ESP32_WROVER_SPARKFUN-IC-POWER_MCP73831; ESP32_WROVER_SPARKFUN-IC-POWER_SOT23-5
PFMF.050.1: ESP32C6_VARISTORCN1812; ESP32C6_VARISTOR_CT/CN1812
Q1, Q2: 20V/4.2A/52mΩ/1.4W; ESP32_WROVER_SPARKFUN-DISCRETESEMI_SOT23-3
Q3: SI1308EDL-T1-GE3; SOT65P210X110-3N
R1, R1_PINH, R1_PINH1, R2_PINH, R2_PINH1, R4, R5, R6, R7, R8, R9, R10: 10K; ESP32_WROVER_EAGLE-LTSPICE_R0402
R1_BAT: 200; ESP32_WROVER_EAGLE-LTSPICE_R0402
R1_PWRUSB: 100k; ESP32_WROVER_EAGLE-LTSPICE_R0402
R2: 2.2; ESP32_WROVER_EAGLE-LTSPICE_R0402
R2-USB1, R2_USB: 5K1; ESP32_WROVER_EAGLE-LTSPICE_R0402
R2_BAT: 2K; ESP32_WROVER_EAGLE-LTSPICE_R0402
R3: 0.47; ESP32_WROVER_EAGLE-LTSPICE_R0402
RESET_BUTTON: BUTTON_CUSYOMV1; MYBUTTON
R_BOOT: 10K; ESP32_WROVER_EAGLE-LTSPICE_R0402
R_CAPACITOR: 15; ESP32_WROVER_EAGLE-LTSPICE_R0402
R_CHANGE: 10K; ESP32_WROVER_EAGLE-LTSPICE_R0402
R_CL1: 10K; ESP32_WROVER_EAGLE-LTSPICE_R0402
R_RESET: 10K; ESP32_WROVER_EAGLE-LTSPICE_R0402
SENSOR2: ESP32_WROVER_BME680_BME680; ESP32_WROVER_BME680_PSON80P300X300X100-8N
SJ1: SJ
TP1, TP2, TP3, TP4, TP5, TP6, TP7, TP8, TP9, TP10, TP11, TP12, TP13, TP14, TP15, TP16, TP17: TPTP20R; TP20R
U1: W25Q512JVEIQ; SON127P600X800X80-9N
U2: ESP32-C6-WROOM-1-N8; XCVR_ESP32-C6-WROOM-1-N8
U3: DS3231SN#; SOIC127P1032X265-16N
U4: MAX17048G+T10; SON50P200X200X80-9N

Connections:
3V3: C1_BAT2.1, C3.+, C9.1, D7.2 (ANODE), IC1.2 (VDD), IC4.5 (VOUT), J3.2, J4.P4 (VDD), Q2.3 (D), R1.2, R1_PINH1.2, R2_PINH1.2, R5.2, R6.2, R7.2, R8.2, R9.2, R10.2, R_BOOT.2, R_CHANGE.2, R_CL1.2, R_RESET.2, TP16.TP, U1.3 (!WP!(IO2)), U1.7 (!HOLD!/!RESET!(IO3)), U1.8 (VCC), U2.2 (3V3), U3.2 (VCC)
32KHZ: R2_PINH1.1, U2.9 (IO1), U3.1 (32KHZ)
DN: D1.4 (I/O2_2), J2.A7, J2.B7
DP: D1.6 (I/O1_2), J2.A6, J2.B6
EPD_3V3: C7.1, EPD_C5.1, J1.15, J1.16, L1.2, Q2.2 (S), TP17.TP
EPD_3V3_C: Q2.1 (G), R_CL1.1, TP13.TP, U2.18 (IO20)
EPD_BUSY: J1.9, TP9.TP, U2.26 (IO3)
EPD_CS: D6.2, J1.12, R9.1, TP10.TP, U2.11 (IO10)
EPD_DC: J1.11, TP11.TP, U2.5 (IO5)
EPD_RST: J1.10, TP12.TP, U2.21 (IO23)
FLASH_CS: D9.2, R5.1, U1.1 (!CS), U2.12 (IO11)
GDR: J1.2, Q3.1 (G), R4.2
GND: BOOT_BUTTON.1, BOOT_BUTTON.2, C1.2, C1_BAT.2, C1_BAT1.2, C1_BAT2.2, C2.2, C2_BAT.2, C3.-, C4_USB.2, C5.2, C5_USB.2, C6.2, C7.2, C8.2, C9.2, C10.2, C10_SUPERCAP.1, CHANGE_BUTTON.1, CHANGE_BUTTON.2, C_DELAY.2, D1.2 (GND), D3.1 (K), D6.1, D8.1, D9.1, D10.1, D11.1, D12.1, EPD_C1.2, EPD_C2.2, EPD_C5.2, EPD_C6.2, EPD_C7.2, EPD_C8.2, EPD_C9.2, EPD_C10.2, EPD_C11.2, EPD_C12.2, IC1.3 (GND), IC4.2 (VSS), J1.8, J1.17, J1.MP1, J1.MP2, J2.A1, J2.A12, J2.B1, J2.B12, J2.MP1, J2.MP2, J2.MP3, J2.MP4, J3.1, J4.G1 (GND_1), J4.G2 (GND_2), J4.G3 (GND_3), J4.G4 (GND_4), J4.P6 (VSS), MCP73831.2 (VSS), R1_PWRUSB.1, R2.1, R2-USB1.1, R2_BAT.1, R2_USB.2, R4.1, RESET_BUTTON.1, RESET_BUTTON.2, SENSOR2.1 (GND), SENSOR2.5 (SDO), SENSOR2.7 (GND), SJ1.1, TP4.TP, TP5.TP, U1.4 (GND), U1.9 (EXP), U2.1 (GND), U2.28 (GND), U2.29_1 (GND), U2.29_2 (GND), U2.29_3 (GND), U2.29_4 (GND), U2.29_5 (GND), U2.29_6 (GND), U2.29_7 (GND), U2.29_8 (GND), U2.29_9 (GND), U3.13 (GND), U4.1 (CTG), U4.4 (GND), U4.6 (QSTRT), U4.9 (EP)
GPIO8: R1.1, U2.10 (IO8)
I2C_PW: C1.1, C2.1, R1_PINH.2, R2_PINH.2, SENSOR2.2 (CSB), SENSOR2.6 (VDDIO), SENSOR2.8 (VDD), U2.17 (IO19)
INT_RTC: R1_PINH1.1, TP15.TP, U2.8 (IO0), U3.3 (SQW/!INT)
IO/BOOT: BOOT_BUTTON.3, BOOT_BUTTON.4, C6.1, R_BOOT.1, U2.15 (IO9)
IO/CHANGE: C10.1, CHANGE_BUTTON.3, CHANGE_BUTTON.4, R_CHANGE.1, U2.23 (IO15)
MISO: D12.2, J4.P7 (DAT0), R8.1, TP6.TP, U1.2 (DO(IO1)), U2.27 (IO2)
MOSI: D11.2, J1.14, J4.P3 (CMD), R7.1, TP7.TP, U1.5 (DI(IO0)), U2.7 (IO7)
unnamed: J2.B5, R2_USB.1
unnamed: J2.A5, R2-USB1.2
unnamed: MCP73831.1 (STAT), R1_BAT.2
unnamed: CHG_LED.C, R1_BAT.1
unnamed: C_DELAY.1, IC1.5 (CT)
unnamed: C1_BAT1.1, D2.1 (CATHODE), IC4.1 (VIN), IC4.3 (CE), Q1.2 (S)
unnamed: MCP73831.5 (PROG), R2_BAT.2
unnamed: C4.1, D3.2 (A), D4.1 (K)
unnamed: EPD_C10.1, J1.22
unnamed: EPD_C1.1, J1.4
unnamed: EPD_C12.1, J1.24
unnamed: EPD_C8.1, J1.20
unnamed: EPD_C7.1, J1.19
unnamed: D7.1 (CATHODE), R_CAPACITOR.1
unnamed: EPD_C6.1, J1.18
unnamed: EPD_C2.1, J1.5
PREVGH: D5.1 (K), EPD_C9.1, J1.21
PREVGL: D4.2 (A), EPD_C11.1, J1.23
RESE: J1.3, Q3.2 (S), R3.2
RESE': R2.2, R3.1, SJ1.2
RESET: C5.1, IC1.1 (VOUT), RESET_BUTTON.3, RESET_BUTTON.4, R_RESET.1, U2.3 (EN)
RTC_RST: U2.16 (IO18), U3.4 (!RST)
RX: TP2.TP, U2.24 (RXD0/GPIO17)
SCK: D10.2, J1.13, J4.P5 (CLK), R6.1, TP8.TP, U1.6 (CLK), U2.6 (IO6)
SCL: J3.4, R2_PINH.1, SENSOR2.4 (SCK), U2.20 (IO22), U3.16 (SCL), U4.7 (SCL)
SDA: J3.3, R1_PINH.1, SENSOR2.3 (SDI), U2.19 (IO21), U3.15 (SDA), U4.8 (SDA)
SRC: C4.2, D5.2 (A), L1.1, Q3.3 (D)
SS_SD: D8.2, J4.P2 (CD/DAT3), R10.1, U2.4 (IO4)
TX: TP1.TP, U2.25 (TXD0/GPIO16)
USB_D+: D1.1 (I/O1_1), U2.14 (IO13)
USB_D-: D1.3 (I/O2_1), U2.13 (IO12)
VBAT: C2_BAT.1, MCP73831.3 (VBAT), Q1.3 (D), TP3.TP, U4.2 (CELL), U4.3 (VDD)
VBUS: C1_BAT.1, C4_USB.1, C5_USB.1, CHG_LED.A, D1.5 (VBUS), D2.2 (ANODE), MCP73831.4 (VIN), PFMF.050.1.2, Q1.1 (G), R1_PWRUSB.2, TP14.TP
VRTC: C8.1, C10_SUPERCAP.2, R_CAPACITOR.2, U3.14 (VBAT)
VUSB: J2.A4, J2.A9, J2.B4, J2.B9, PFMF.050.1.1

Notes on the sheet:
SD0805S020S1R0
DMG2305UX-7
USB C connector & ESD protection
LDO Voltage Regulator
SD Card
ESP32 C6
Li-Po Battery Charging Controller
E-Paper Drive Circuit
Display Type Selector
E-Paper Display Header
RTC Module DS3231SN
EPD Power
Environmental Sensor BME688
Test Pads
Qwiic / Stemma QT
Voltage Supervisor + Reset & Boot / IO Button
SPI ESD Protection Lines
Battery ChargeLevel
External NORFlash64MB

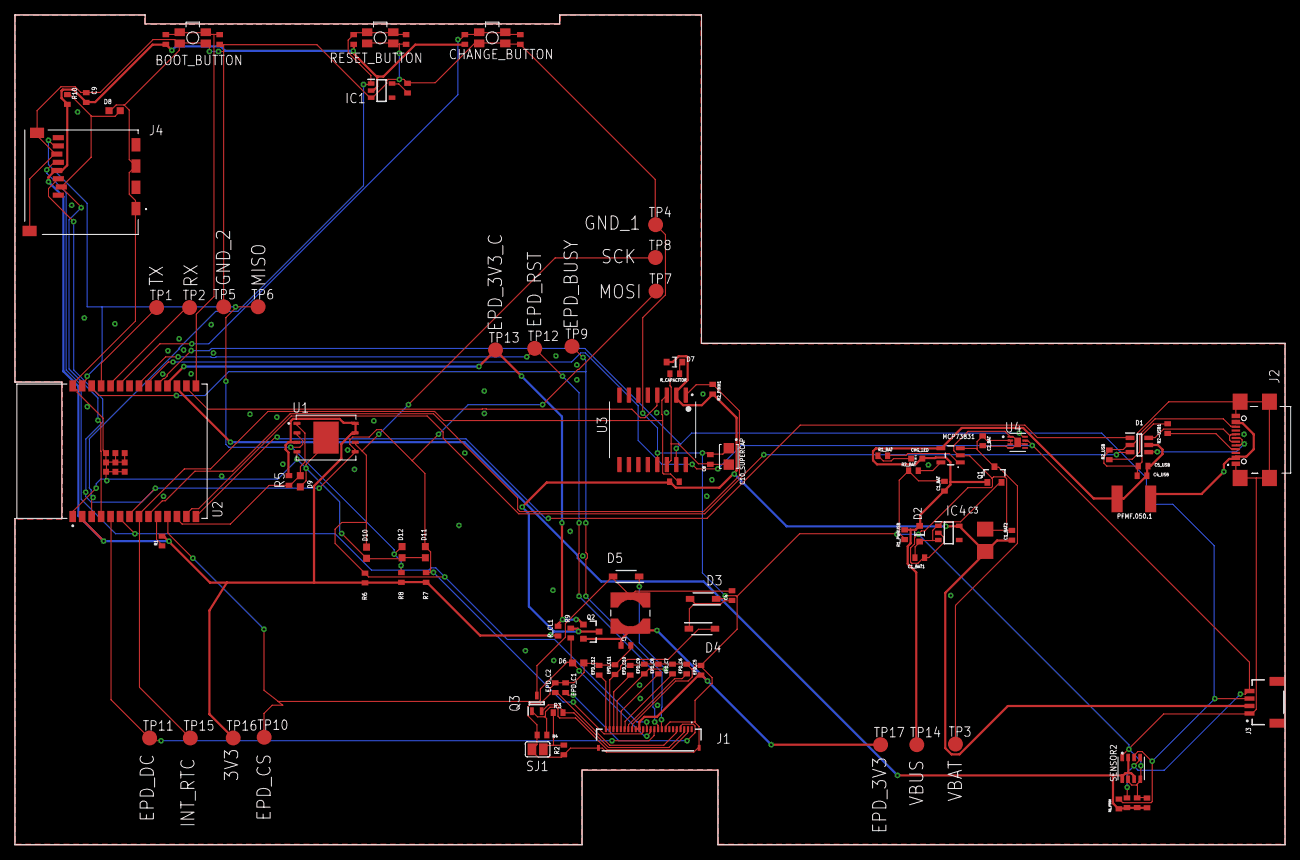
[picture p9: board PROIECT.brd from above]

Board: 2 copper layers, 170.2 x 111.2 mm, 103 parts (0 on the bottom side), 55 nets.

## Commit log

2025-04-11 update files after issues
    [PROIECT.brd, PROIECT.sch]
2025-04-11 Added in BOM C3 component & display

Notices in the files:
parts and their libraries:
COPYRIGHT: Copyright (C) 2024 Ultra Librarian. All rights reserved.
